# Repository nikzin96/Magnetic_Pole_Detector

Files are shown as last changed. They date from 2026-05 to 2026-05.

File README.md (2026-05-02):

# 🧲 Magnetic Pole Detector

<div align="center">
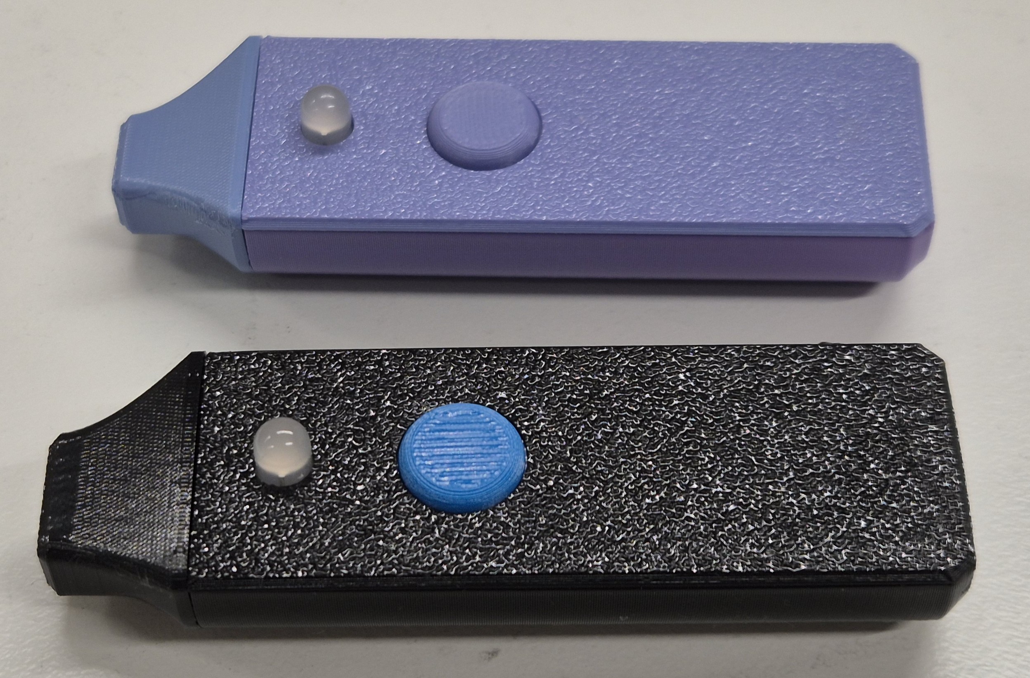
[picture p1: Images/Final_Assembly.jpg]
Magnetic Pole Detector Device
  
</div>

## Overview

A compact, handheld device for quickly identifying the polarity of magnets.

**Key Features:**
- 🔴 **Red LED** = North Pole detected
- 🔵 **Blue LED** = South Pole detected  
- 🟢 **Green LED** = Device powered on
- 🔋 USB-C rechargeable with integrated charging and protection circuit
- 📦 Fully 3D-printable enclosure with tool-free assembly
- ⚡ Analog-only design (no programming required)

## How It Works

Simply hold the power button to activate the device. When the tip approaches a magnet:
- The RGB LED changes color based on which magnetic pole it detects
- Completely passive and safe operation
- Instant visual feedback

<div align="center">
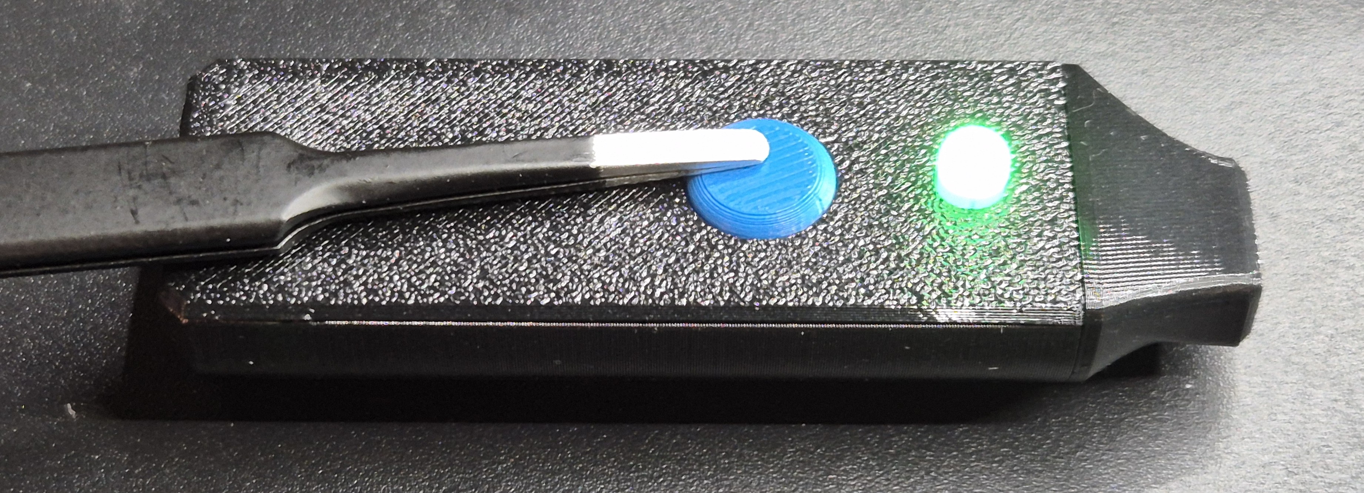
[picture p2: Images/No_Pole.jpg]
Device powered on (green)
  
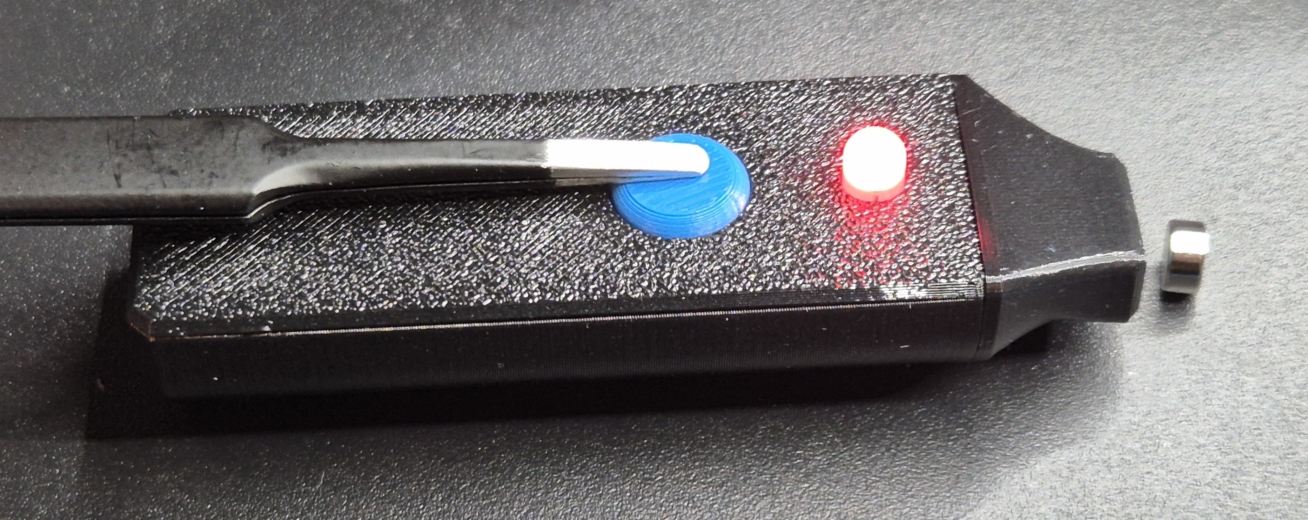
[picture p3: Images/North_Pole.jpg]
North pole detected (red)
  
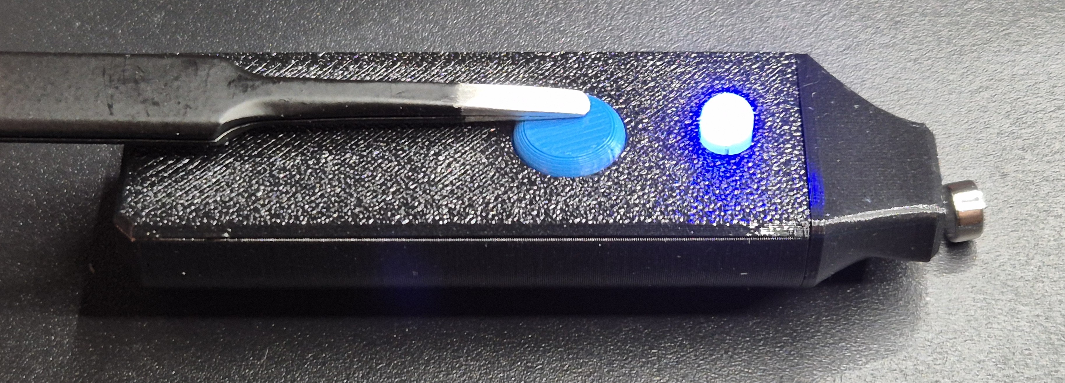
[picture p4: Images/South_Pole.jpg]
South pole detected (blue)
  
</div>

## Specifications

| Feature | Details |
|---|---|
| **Battery** | 200 mAh LiPo (501240 or similar, max 5mm thick × 12mm wide) |
| **Charging** | USB-C, integrated TP4056 charging circuit |
| **Undervoltage Cutoff** | ~3V |
| **Design** | Fully analog circuit (no programming required) |
| **Enclosure** | 3D-printed plastic, tool-free click-fit assembly |

## Electronics

The device uses a purely analog circuit design, eliminating the complexity and power consumption of a microcontroller.

**Key Components:**
- **Charging & Protection:** TP4056-based LiPo charging circuit with built-in protection
- **Sensor:** Hall effect sensor for magnetic field detection
- **Output:** RGB LED for user feedback

**Battery Notes:**
- I recommend using a pre-protected LiPo cell from a reputable supplier
- Any LiPo cell ≤5mm thick and ≤12mm wide should fit
- Using the JST 2.0 PH connector does currently not fit into the case. Solder the battery directly to the pads.
- For smaller capacity batteries, adjust charging current by modifying R4 resistor value

⚠️ **If you do not want to use a lithium cell, the device could be modified to use only USB-Power or a standard AA or AAA battery. If there is interest in changes like this please let me know by opening an issue.**

**Documentation & PCB:**
- Schematic available as PDF
- EasyEDA Pro project file included
- Gerber files and complete BOM ready for PCB ordering
- All files located in the `PCB/` folder

## Assembly

### 3D Printing

The enclosure is designed for tool-free assembly with precision-fit click joints.

**Print Settings:**
- **Main body:** Print standing upright (USB hole facing downward) using 0.2mm layer height
- **Tip:** Use finer 0.12mm layer height
- **Material:** Standard PLA or PETG works well
- **No supports needed** for the click-fit design

### Assembly Steps

1. Print all case parts from files in `CAD/` folder
2. Use the BendTemplate to bend the hall effect sensors into the right shape (one facing forward one backwards)
3. Assemble the PCB including the battery (double check polarity!)
4. Insert the PCB assembly into the main body
5. Insert the button cap into the hole in the cover
6. Add the cover to the main body by clicking it into place 
7. Close the front using the click-fit mechanism
8. Charge via USB-C before first use

<div align="center">
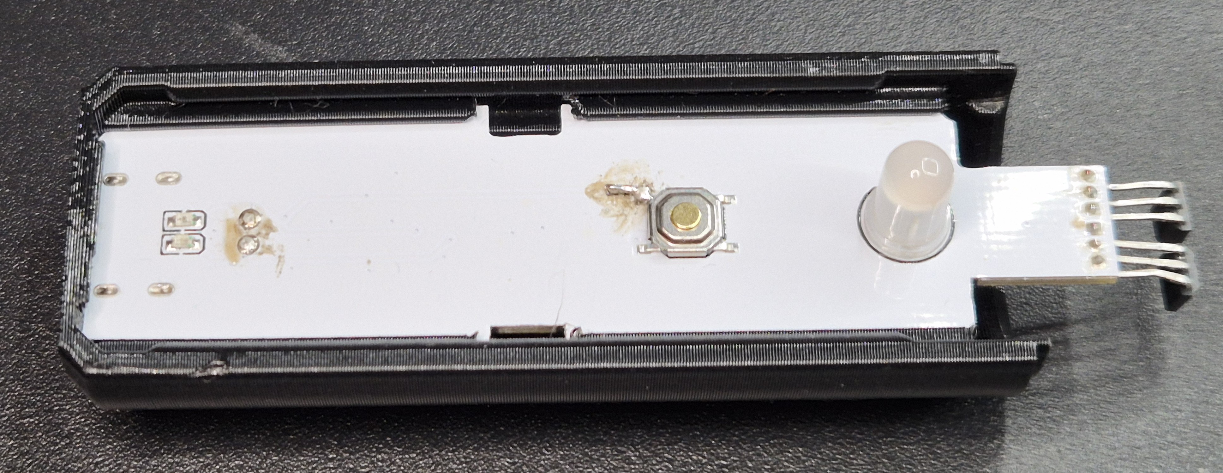
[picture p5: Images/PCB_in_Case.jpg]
PCB in main case body
  
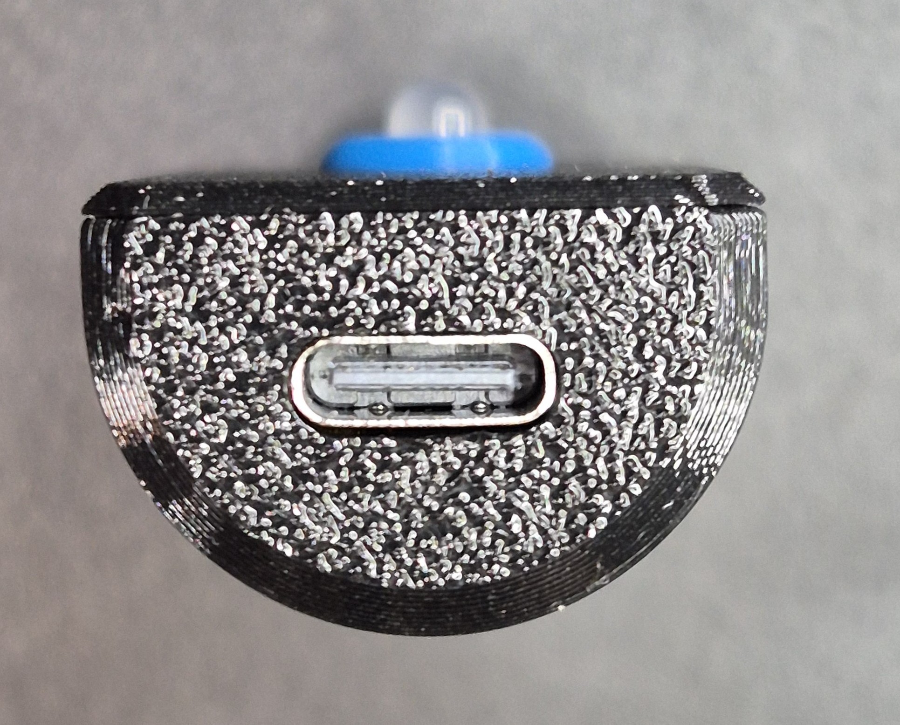
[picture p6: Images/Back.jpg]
Back view showing USB-C charging port
  
</div>

## Project Files

- **`CAD/`** – 3D model files for case printing
- **`PCB/`** – Schematic, EasyEDA project, Gerber files, and BOM
- **`Images/`** – Reference photos

## Building This Project

This is a hobby project designed to be accessible for makers and electronics enthusiasts. All necessary files are provided to build your own detector.

## ⚠️ Disclaimer & Safety Warning

**This is a hobby project, not a commercial product.** Use at your own risk.

### Lithium Battery Safety

Working with lithium-ion/lithium-polymer batteries carries inherent risks including but not limited to:
- **Fire and explosion hazards** if damaged, short-circuited, or improperly charged
- **Toxic chemical exposure** from cell rupture or leakage
- **Thermal runaway** leading to rapid heat generation and potential injury

**Only attempt this project if you:**
- Have prior experience with lithium battery handling and safety protocols
- Understand the risks and accept full responsibility for those risks
- Have access to proper charging and testing equipment
- Can work in a safe environment with appropriate fire suppression nearby
- Comply with all local regulations regarding lithium battery transportation and storage

**I strongly recommend:** Using a pre-protected LiPo cell (with built-in protection circuit) from a reputable supplier. Do not attempt to use bare cells without proper protection circuitry.

### Liability Disclaimer

I provide this project "as-is" without warranties of any kind, express or implied. **I am not responsible for:**
- Injuries or burns resulting from battery failure or mishandling
- Property damage caused by fire, explosion, or chemical leakage
- Damage to equipment or devices
- Any direct, indirect, incidental, or consequential damages arising from your use of this project
- Regulatory violations or fines related to battery handling in your jurisdiction

**By building this project, you assume all liability and risk.**

If you are inexperienced with lithium batteries or electronics, **consult with a qualified professional before proceeding.**

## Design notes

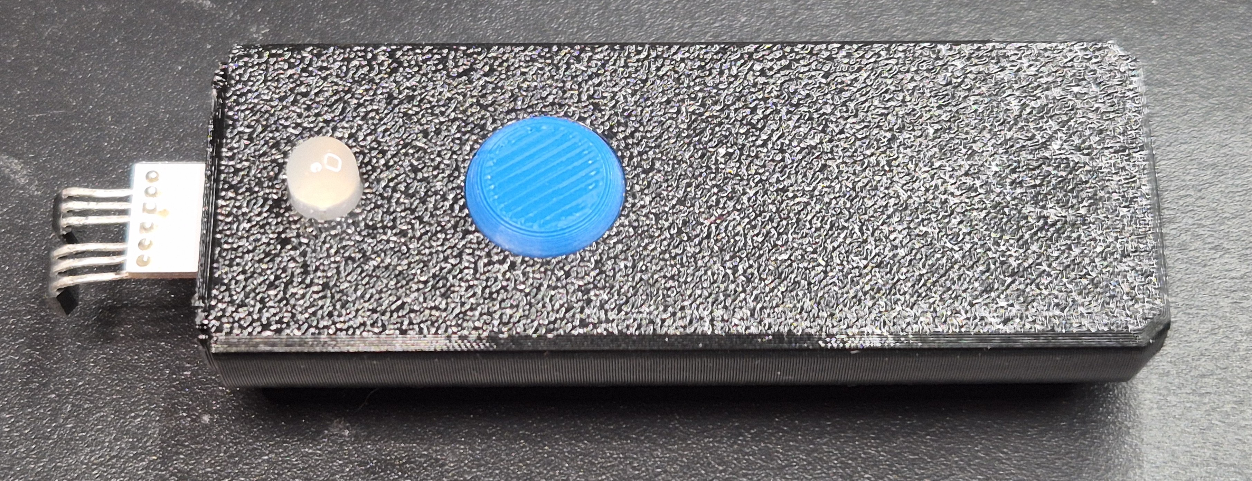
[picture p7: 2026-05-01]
Images/Missing_Tip.jpg

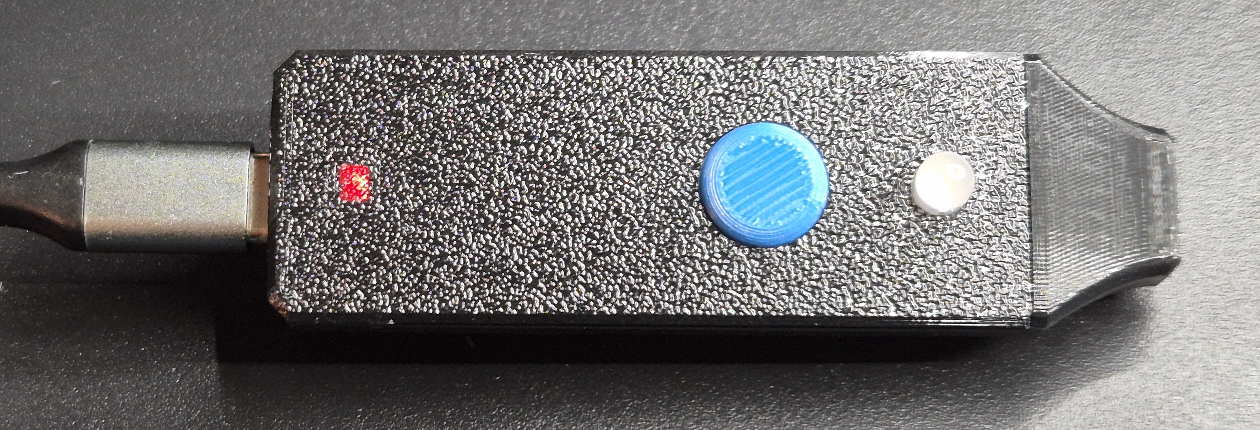
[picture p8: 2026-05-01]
Images/Charging.jpg

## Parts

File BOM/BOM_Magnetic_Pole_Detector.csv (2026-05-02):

Quantity | Part | Remarks
1 | Assembled PCB | -
1 | 501240 LiPo with protection board | 200 mAh not wider than 12 mm and not thicker than 5 mm
1 | 3D printed Case | -

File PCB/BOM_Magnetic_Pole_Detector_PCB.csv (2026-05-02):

Quantity | Designator | Value | Footprint | Remarks
3 | C1,C2,C3 | 100nF | C0402 | -
3 | C4,C5,C6 | 1uF | C0402 | -
1 | LED1 | Red | 0603 | -
1 | LED2 | Green | 0603 | -
1 | LED3 | LED 5mm RGB | 5MM RGB TRI-COLOR LED 1.25MM PINS | Common anode LED
3 | R1,R2,R11 | 1k | R0402 | -
3 | R4,R5,R6 | 5k1 | R0402 | -
2 | R9,R10 | 10k | R0402 | -
2 | R7,R12 | 634R | R0402 | -
1 | R3 | 470R | R0402 | -
1 | R8 | 2k7 | R0402 | -
1 | U1 | TP4056 | ESOP-8_L4.9-W3.9-P1.27-LS6.0-BL-EP | -
1 | U2 | S-8261ABJMD-G3JT2G | SOT-23-6_L2.9-W1.6-P0.95-LS2.8-TL | -
1 | Q1 | FS8205A | SOT-23-6_L2.9-W1.6-P0.95-LS2.8-BR | -
2 | U4,U5 | A3144EUA-T-JSM | TO-92S-3_L4.1-W1.7-P1.27-L | -
1 | U3 | SN74LVC1G38DCKR | SC-70-5_L2.1-W1.3-P0.65-LS2.1-BL | -
1 | U6 | REG71050DRVR | WSON-6_L2.0-W2.0-P0.65-TL-EP | -
1 | USB1 | HC-TYPE-C-6P-01A | USB-C-SMD_HC-TYPE-C-6P-01A | -
1 | CN1 | B2B-PH-K-S(LF)(SN) | CONN-TH_B2B-PH-K-S | optional in the current version of the case the connector does not fit

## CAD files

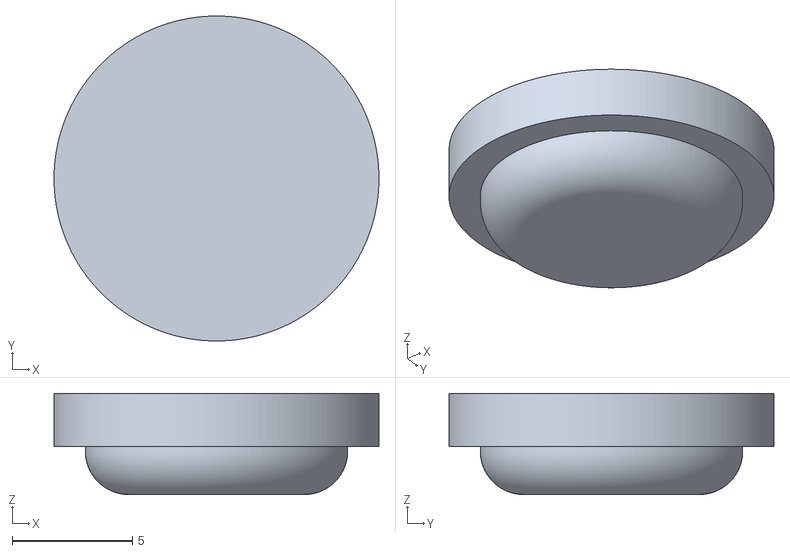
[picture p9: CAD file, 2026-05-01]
CAD/MagneticPoleDetector - ButtonCap.stl
13.5 x 13.5 x 4.20

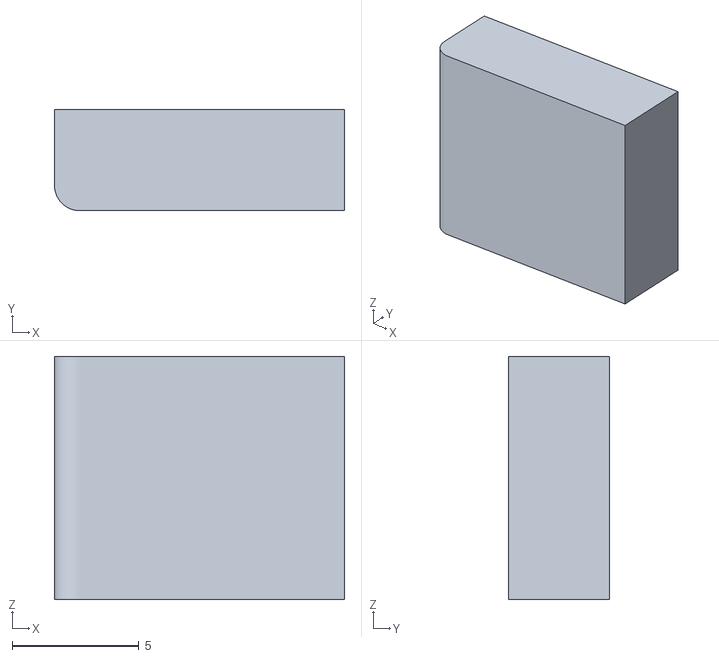
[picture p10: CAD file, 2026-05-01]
CAD/BendTemplate - TopPiece.stl
11.4 x 4.00 x 9.60

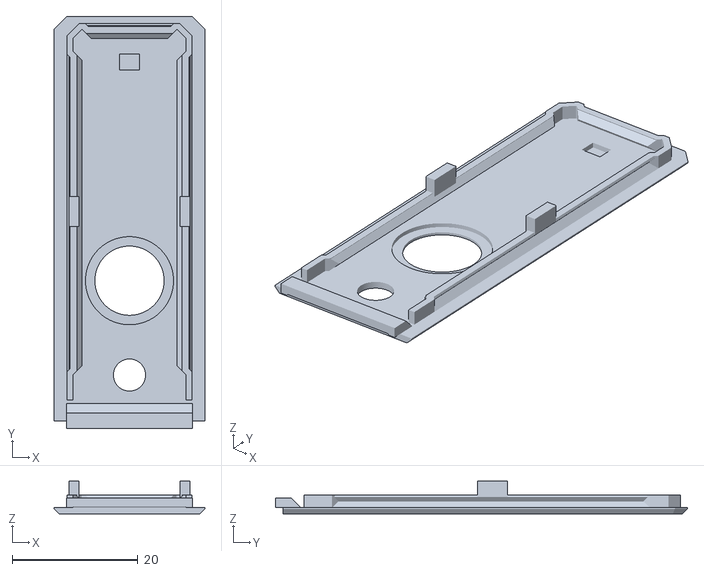
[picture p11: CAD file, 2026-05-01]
CAD/MagneticPoleDetector - Lid.stl
24.0 x 65.5 x 5.20

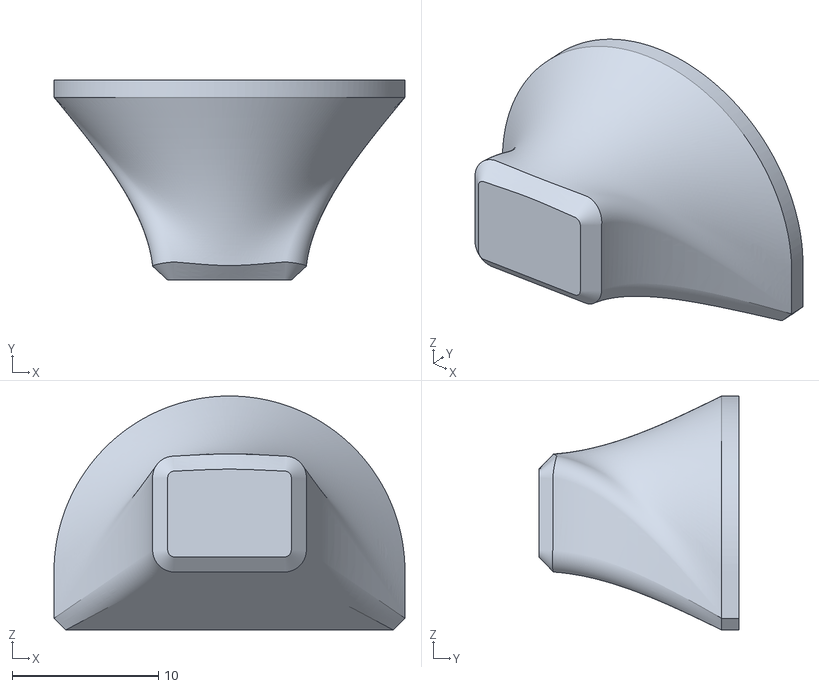
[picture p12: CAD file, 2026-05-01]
CAD/MagneticPoleDetector - Front.stl
24.0 x 13.7 x 16.0

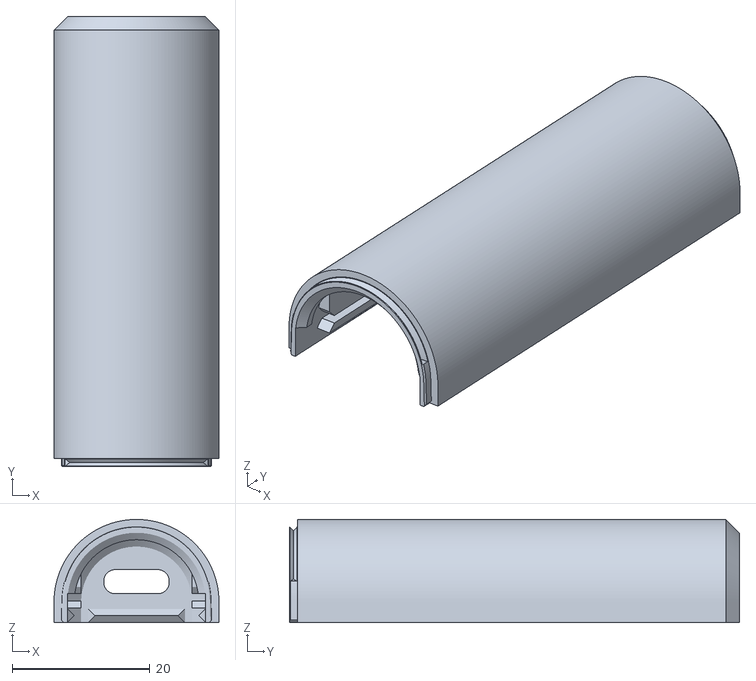
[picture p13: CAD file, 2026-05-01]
CAD/MagneticPoleDetector - Base.stl
24.0 x 65.5 x 15.0

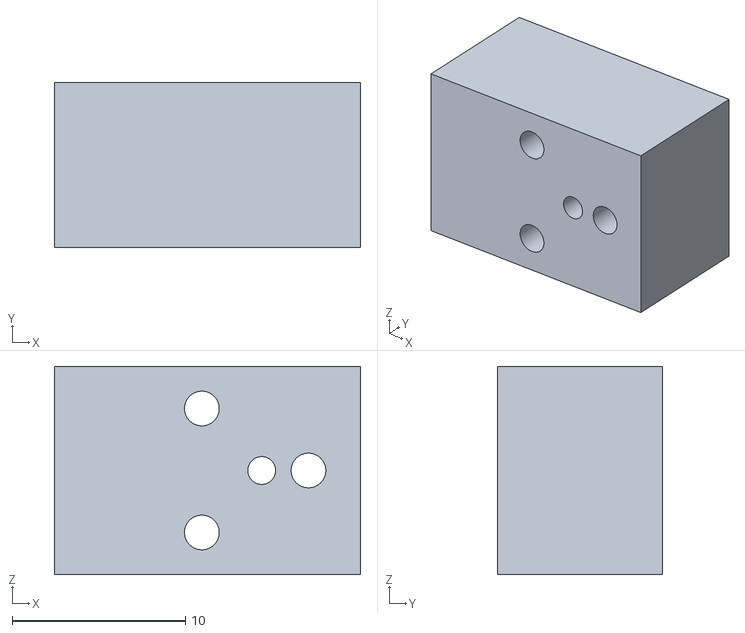
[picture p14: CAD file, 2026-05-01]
CAD/BendTemplate - BottomPiece.stl
17.6 x 9.50 x 12.0

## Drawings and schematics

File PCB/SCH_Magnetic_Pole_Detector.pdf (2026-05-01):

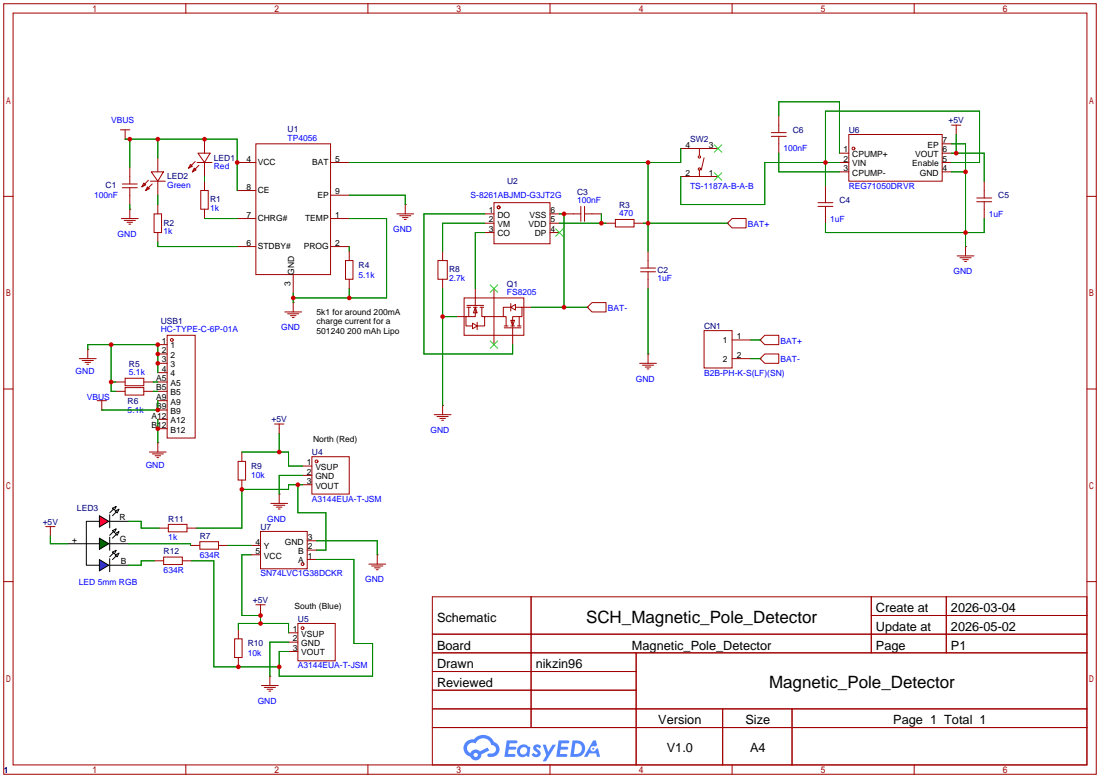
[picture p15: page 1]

Schematic | SCH_Magnetic_Pole_Detector | Create at | 2026-03-04

Update at | 2026-05-02

Board | Magnetic_Pole_Detector | Page | P1
Drawn | nikzin96 | Magnetic_Pole_Detector
Reviewed

Version | Size | Page 1 Total 1
V1.0 | A4

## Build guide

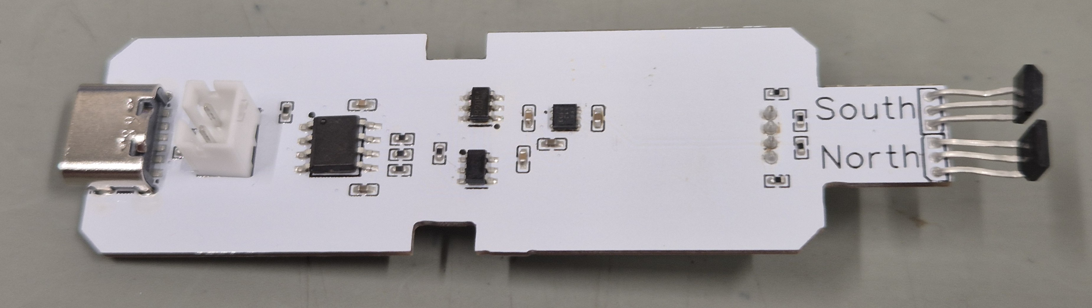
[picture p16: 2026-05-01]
Images/Assembled_PCB_Bottom.jpg

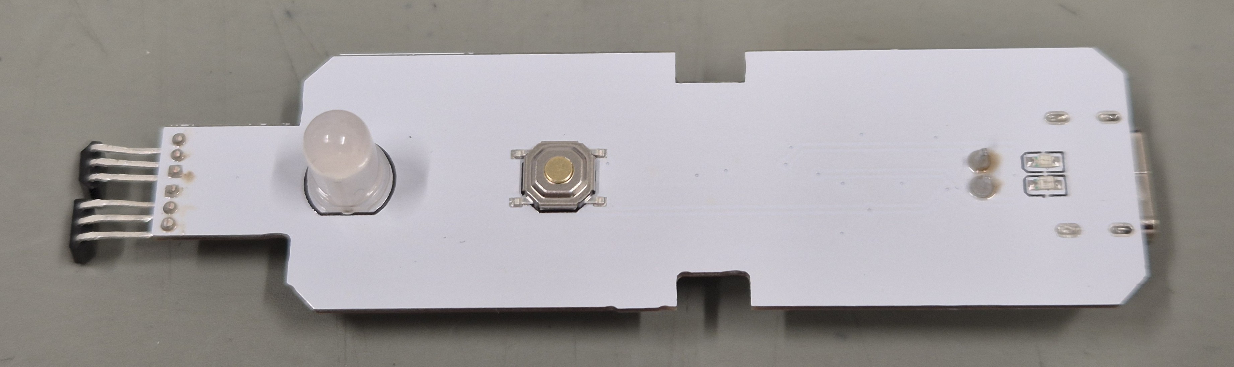
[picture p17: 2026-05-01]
Images/Assembled_PCB_Top.jpg

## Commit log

2026-05-01 add project files
    [BOM_Magnetic_Pole_Detector.csv, BOM_Magnetic_Pole_Detector_PCB.csv, BendTemplate - BottomPiece.stl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]
2026-05-01 update csv, schematic and readme
    [BOM_Magnetic_Pole_Detector.csv, BOM_Magnetic_Pole_Detector_PCB.csv]
2026-05-02 update CSV
    [BOM_Magnetic_Pole_Detector.csv, BOM_Magnetic_Pole_Detector_PCB.csv]
2026-05-02 update lipo information in csv and readme
    [BOM_Magnetic_Pole_Detector.csv]
